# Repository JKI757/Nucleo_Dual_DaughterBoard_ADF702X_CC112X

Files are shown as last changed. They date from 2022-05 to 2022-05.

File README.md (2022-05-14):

## About the Project

- This project is a simple PCB for an STM32 Nucleo-64 Hat that provides an interface between the hat and an Analog Devices [ADF-702X](https://www.analog.com/en/design-center/evaluation-hardware-and-software/evaluation-boards-kits/eval-adf7021-n.html) development board and a Texas Instruments [CC112X EMK](https://www.ti.com/tool/CC1120EMK-420-470) development board.

The project includes both the Kicad schematic and PCB files, and the STM project for the Nucleo-64 L452RE.

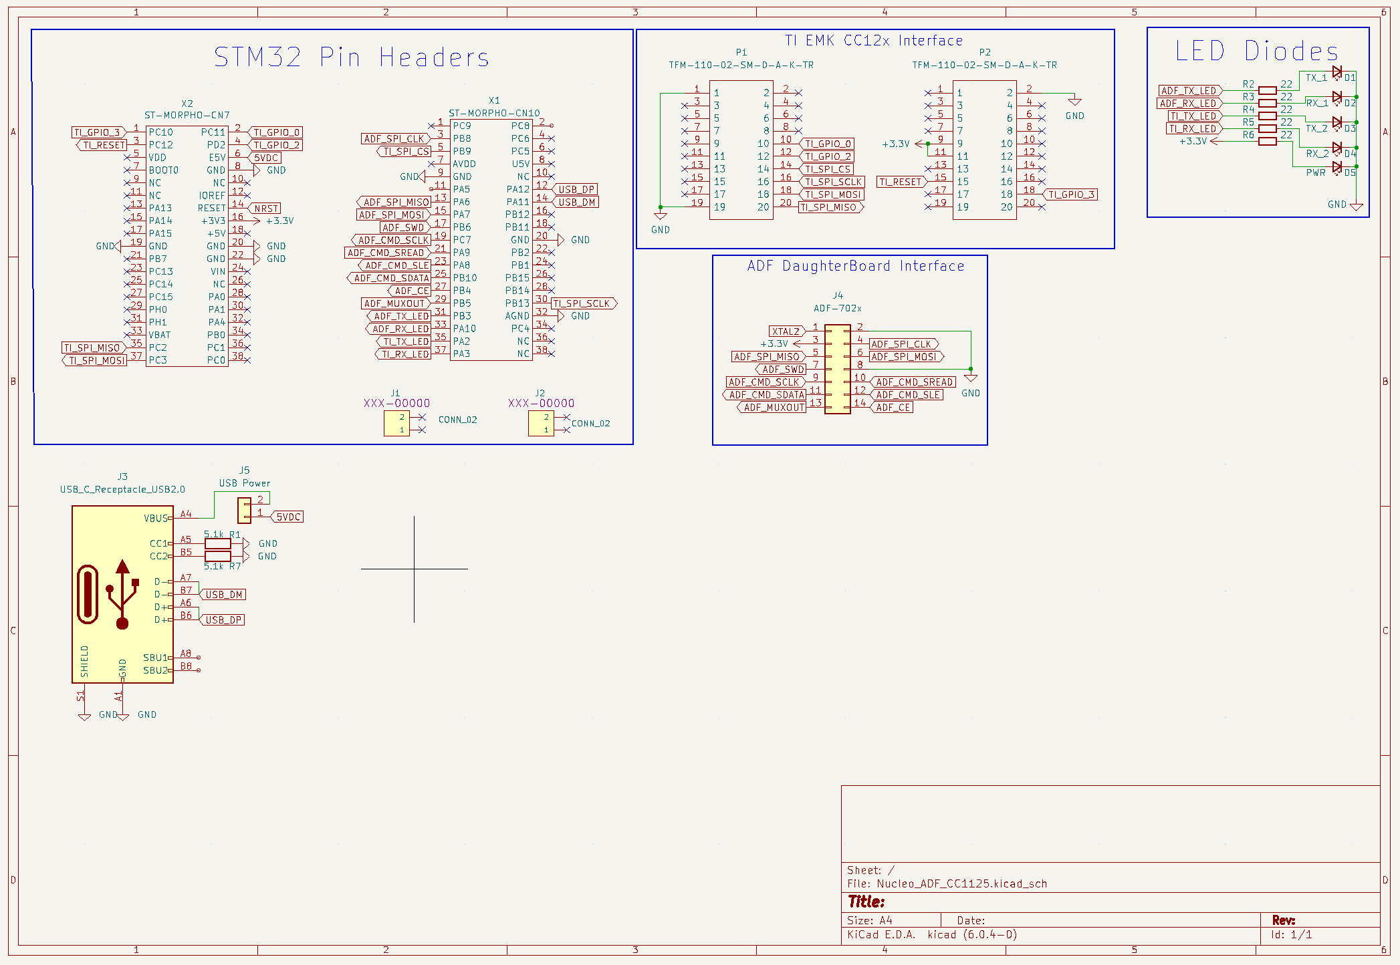
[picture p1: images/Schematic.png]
Schematic


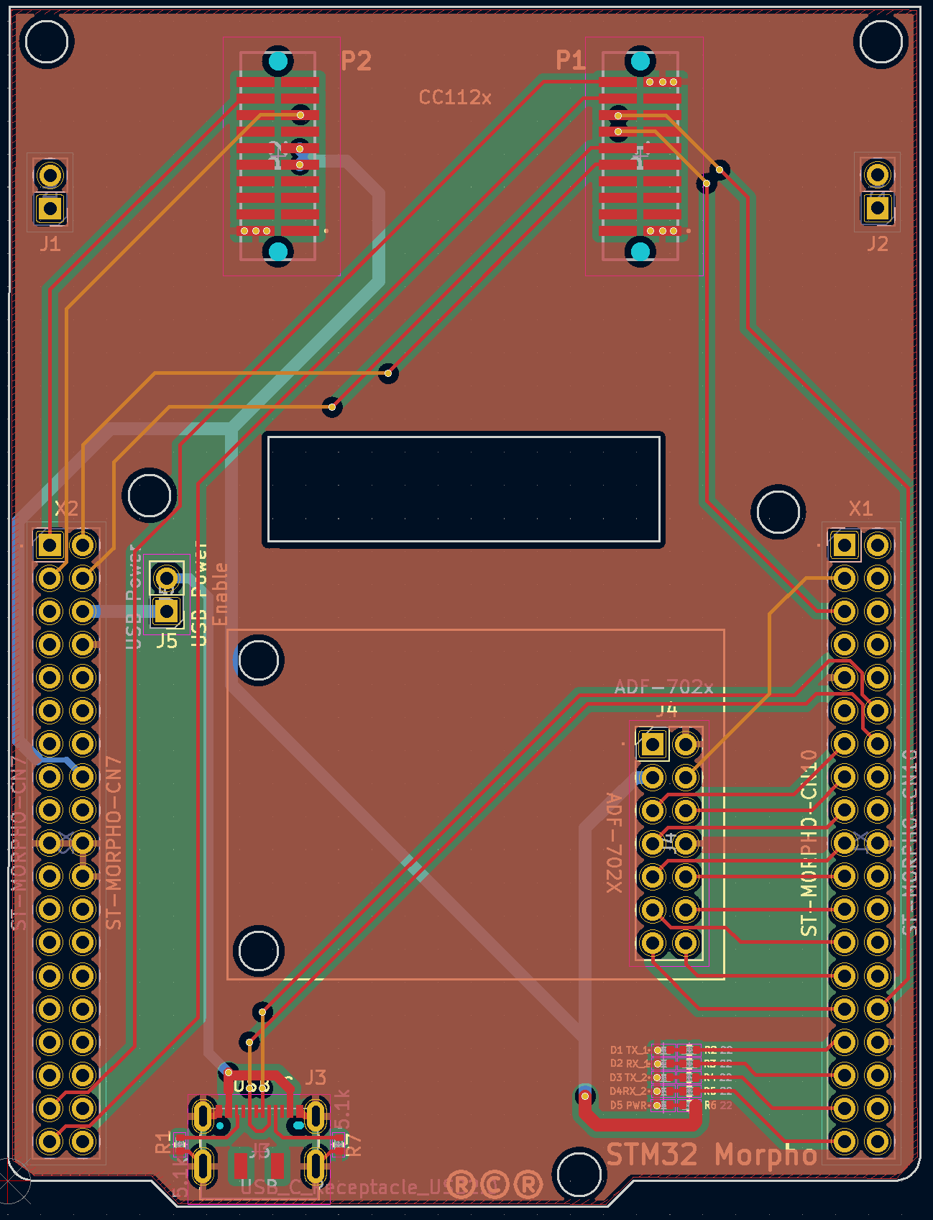
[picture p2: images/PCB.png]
PCB


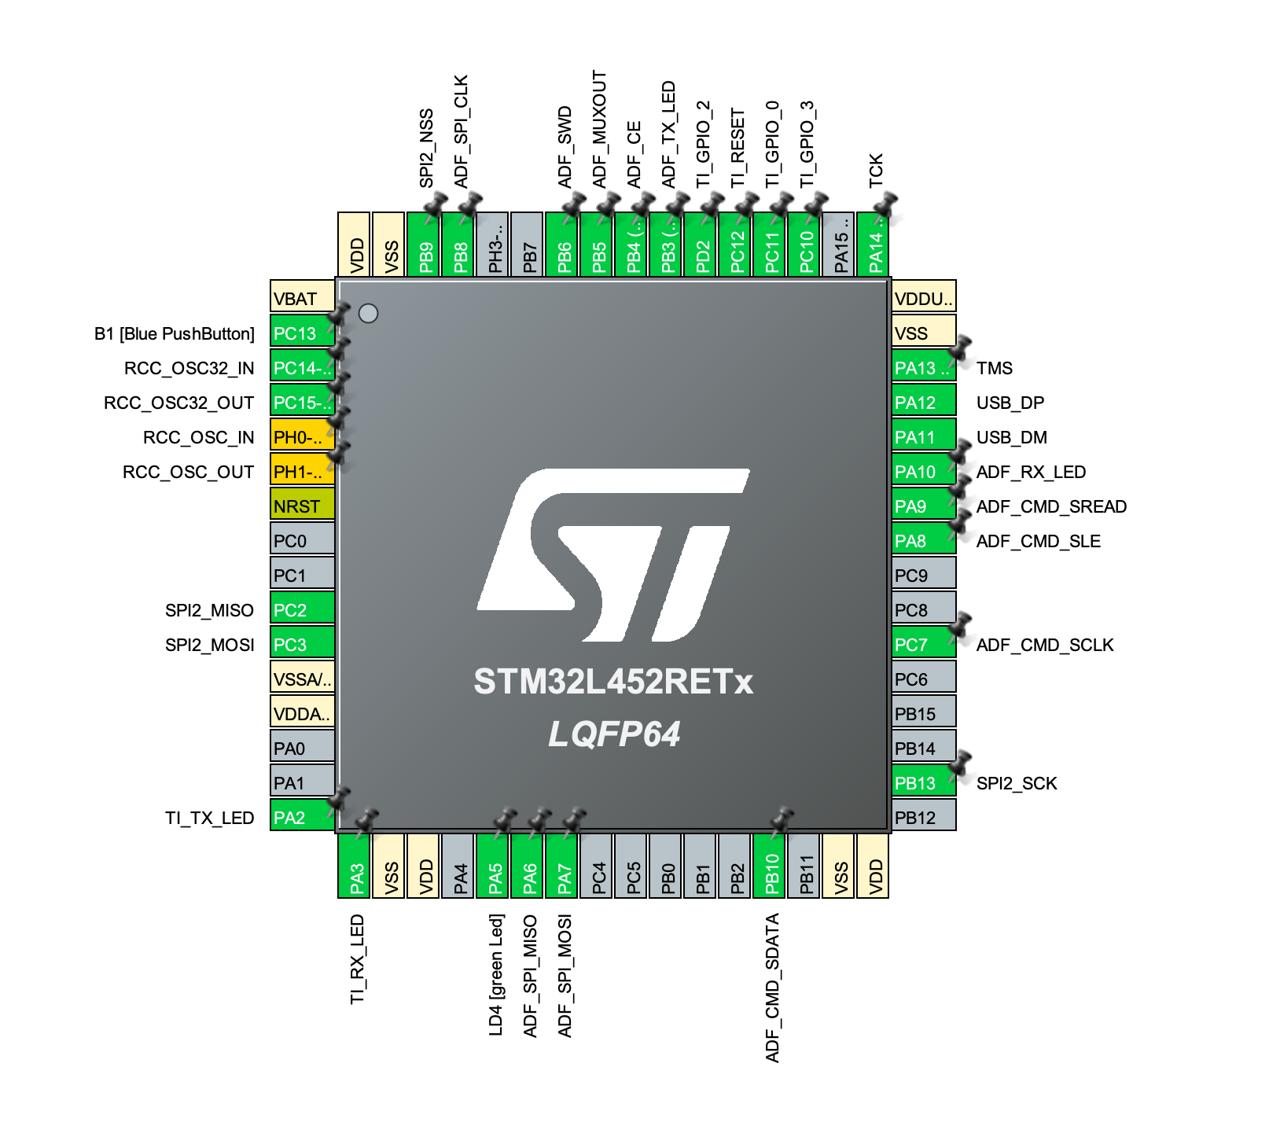
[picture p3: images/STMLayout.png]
Layout STM Layout


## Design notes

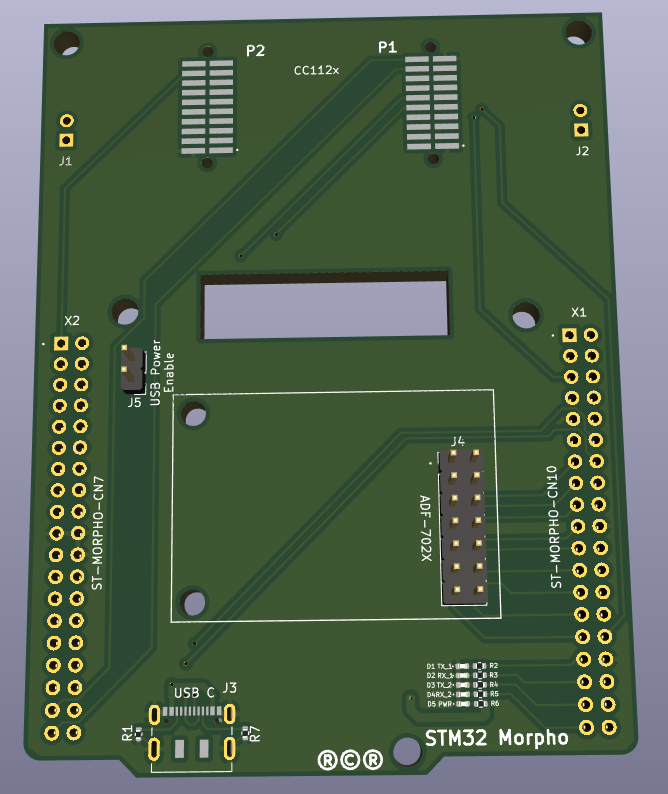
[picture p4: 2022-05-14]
images/3D.png

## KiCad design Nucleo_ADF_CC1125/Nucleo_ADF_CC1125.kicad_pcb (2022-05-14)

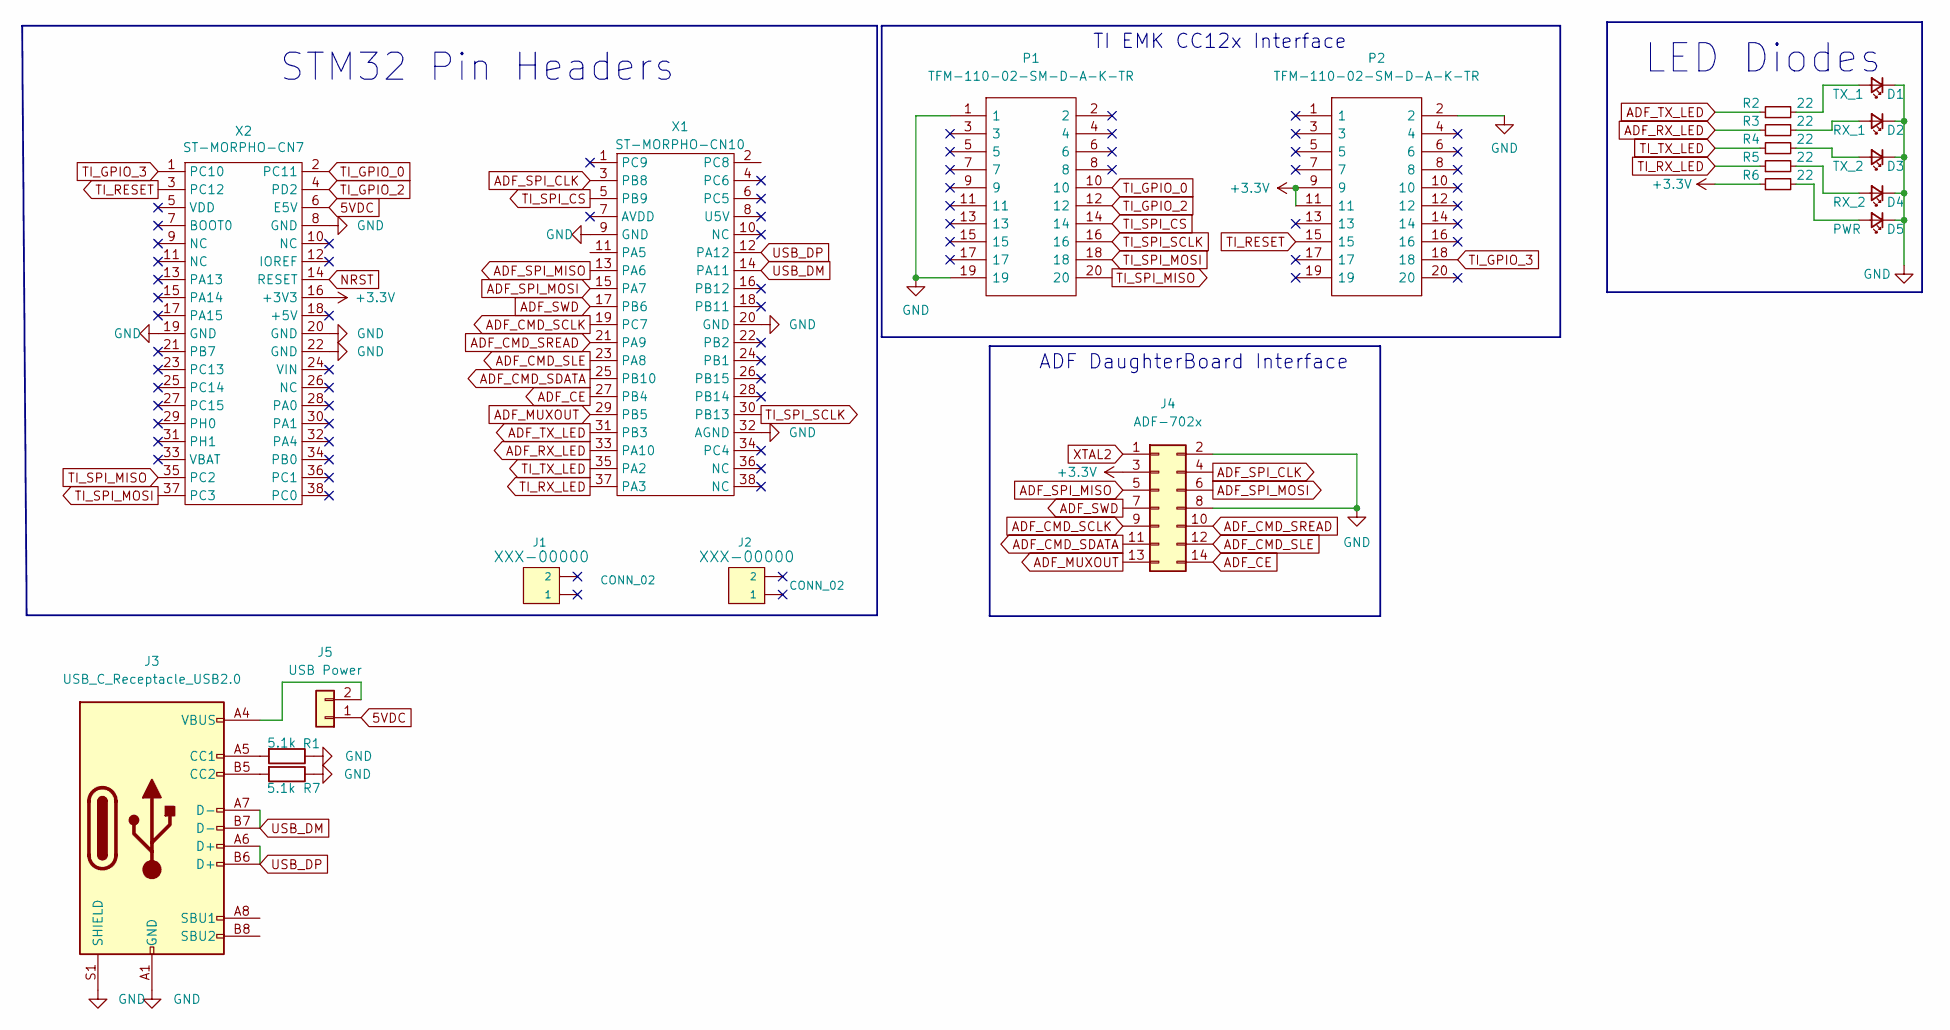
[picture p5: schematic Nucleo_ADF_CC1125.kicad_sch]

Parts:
D1: TX_1; LED_0402_1005Metric
D2: RX_1; LED_0402_1005Metric
D3: TX_2; LED_0402_1005Metric
D4: RX_2; LED_0402_1005Metric
D5: PWR; LED_0402_1005Metric
J1, J2: CONN_02; PinSocket_1x02_P2.54mm_Vertical
J3: USB_C_Receptacle_USB2.0; USB_C_Receptacle_JAE_DX07S016JA1R1500
J4: ADF-702x; PinHeader_2x07_P2.54mm_Vertical
J5: USB Power; PinHeader_1x02_P2.54mm_Vertical
P1, P2: TFM-110-02-SM-D-A-K-TR; TFM-110-02-XXX-D-A-Y-TR; Mouser Part Number 200-TFM11002SMDAKTR
R1, R7: 5.1k; R_0402_1005Metric
R2, R3, R4, R5, R6: 22; R_0402_1005Metric
X1: ST-MORPHO-CN10; PinSocket_2x19_P2.54mm_Vertical
X2: ST-MORPHO-CN7; PinSocket_2x19_P2.54mm_Vertical

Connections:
5VDC: J5.1, X2.6 (E5V)
+3V3: J4.3, P2.9, P2.11, R6.1, X2.16 (+3V3)
ADF_CE: J4.14, X1.27 (PB4)
ADF_CMD_SCLK: J4.9, X1.19 (PC7)
ADF_CMD_SDATA: J4.11, X1.25 (PB10)
ADF_CMD_SLE: J4.12, X1.23 (PA8)
ADF_CMD_SREAD: J4.10, X1.21 (PA9)
ADF_MUXOUT: J4.13, X1.29 (PB5)
ADF_RX_LED: R3.1, X1.33 (PA10)
ADF_SPI_CLK: J4.4, X1.3 (PB8)
ADF_SPI_MISO: J4.5, X1.13 (PA6)
ADF_SPI_MOSI: J4.6, X1.15 (PA7)
ADF_SWD: J4.7, X1.17 (PB6)
ADF_TX_LED: R2.1, X1.31 (PB3)
GND: D1.1 (K), D2.1 (K), D3.1 (K), D4.1 (K), D5.1 (K), J3.A1 (GND), J3.A12 (GND), J3.B1 (GND), J3.B12 (GND), J3.S1 (SHIELD), J4.2, J4.8, P1.1, P1.19, P2.2, R1.1, R7.1, X1.9 (GND), X1.20 (GND), X1.32 (AGND), X2.8 (GND), X2.19 (GND), X2.20 (GND), X2.22 (GND)
NRST: X2.14 (RESET)
unnamed: D1.2 (A), R2.2
unnamed: D2.2 (A), R3.2
unnamed: D3.2 (A), R4.2
unnamed: D4.2 (A), R5.2
unnamed: D5.2 (A), R6.2
unnamed: J3.A4 (VBUS), J3.A9 (VBUS), J3.B4 (VBUS), J3.B9 (VBUS), J5.2
unnamed: J3.A5 (CC1), R1.2
unnamed: J3.B5 (CC2), R7.2
TI_GPIO_0: P1.10, X2.2 (PC11)
TI_GPIO_2: P1.12, X2.4 (PD2)
TI_GPIO_3: P2.18, X2.1 (PC10)
TI_RESET: P2.15, X2.3 (PC12)
TI_RX_LED: R5.1, X1.37 (PA3)
TI_SPI_CS: P1.14, X1.5 (PB9)
TI_SPI_MISO: P1.20, X2.35 (PC2)
TI_SPI_MOSI: P1.18, X2.37 (PC3)
TI_SPI_SCLK: P1.16, X1.30 (PB13)
TI_TX_LED: R4.1, X1.35 (PA2)
USB_DM: J3.A7 (D-), J3.B7 (D-), X1.14 (PA11)
USB_DP: J3.A6 (D+), J3.B6 (D+), X1.12 (PA12)
XTAL2: J4.1

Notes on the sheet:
TI EMK CC12x Interface
STM32 Pin Headers
LED Diodes
ADF DaughterBoard Interface

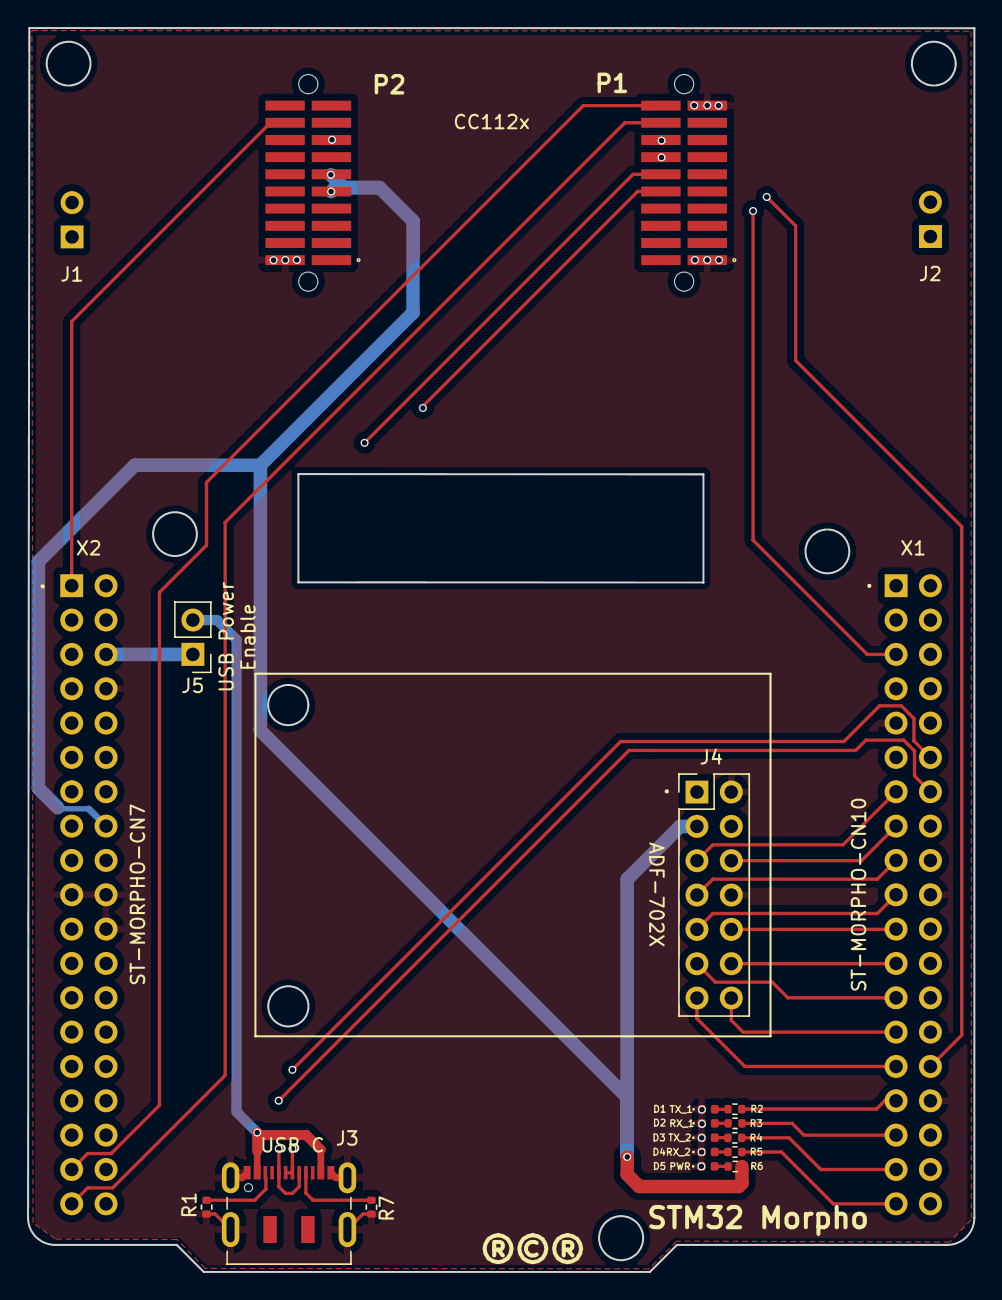
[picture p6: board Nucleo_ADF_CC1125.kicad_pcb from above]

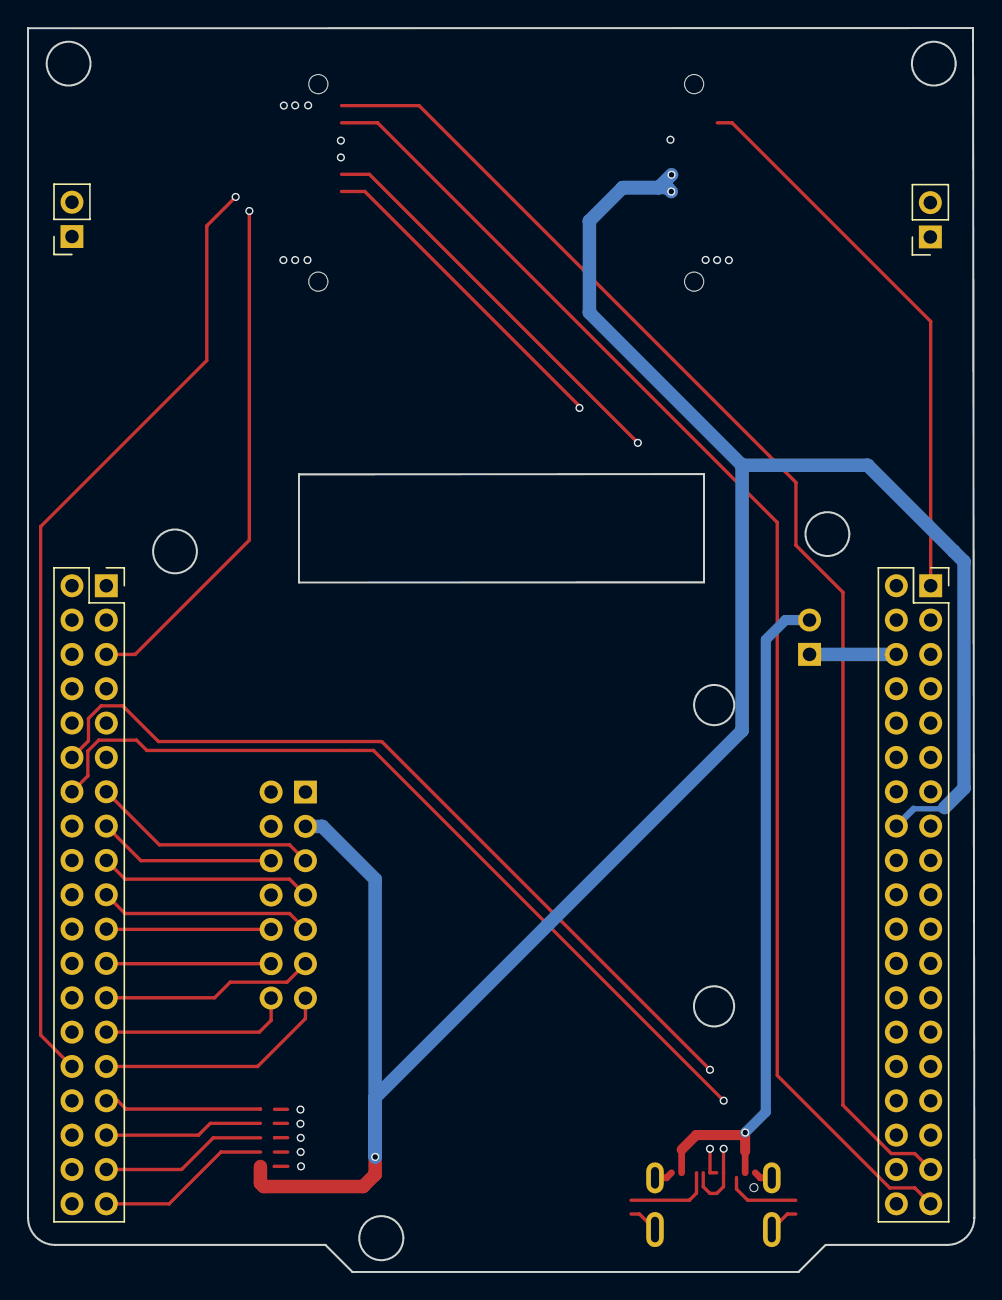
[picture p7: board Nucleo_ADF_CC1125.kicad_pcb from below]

Board: 4 copper layers, 70.0 x 92.0 mm, 21 parts (4 on the bottom side), 35 nets.

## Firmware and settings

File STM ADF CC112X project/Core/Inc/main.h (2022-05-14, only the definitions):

#define B1_Pin LL_GPIO_PIN_13
#define B1_GPIO_Port GPIOC
#define B1_EXTI_IRQn EXTI15_10_IRQn
#define TI_TX_LED_Pin LL_GPIO_PIN_2
#define TI_TX_LED_GPIO_Port GPIOA
#define TI_RX_LED_Pin LL_GPIO_PIN_3
#define TI_RX_LED_GPIO_Port GPIOA
#define LD4_Pin LL_GPIO_PIN_5
#define LD4_GPIO_Port GPIOA
#define ADF_SPI_MISO_Pin LL_GPIO_PIN_6
#define ADF_SPI_MISO_GPIO_Port GPIOA
#define ADF_SPI_MOSI_Pin LL_GPIO_PIN_7
#define ADF_SPI_MOSI_GPIO_Port GPIOA
#define ADF_CMD_SDATA_Pin LL_GPIO_PIN_10
#define ADF_CMD_SDATA_GPIO_Port GPIOB
#define ADF_CMD_SCLK_Pin LL_GPIO_PIN_7
#define ADF_CMD_SCLK_GPIO_Port GPIOC
#define ADF_CMD_SLE_Pin LL_GPIO_PIN_8
#define ADF_CMD_SLE_GPIO_Port GPIOA
#define ADF_CMD_SREAD_Pin LL_GPIO_PIN_9
#define ADF_CMD_SREAD_GPIO_Port GPIOA
#define ADF_RX_LED_Pin LL_GPIO_PIN_10
#define ADF_RX_LED_GPIO_Port GPIOA
#define TMS_Pin LL_GPIO_PIN_13
#define TMS_GPIO_Port GPIOA
#define TCK_Pin LL_GPIO_PIN_14
#define TCK_GPIO_Port GPIOA
#define TI_GPIO_3_Pin LL_GPIO_PIN_10
#define TI_GPIO_3_GPIO_Port GPIOC
#define TI_GPIO_3_EXTI_IRQn EXTI15_10_IRQn
#define TI_GPIO_0_Pin LL_GPIO_PIN_11
#define TI_GPIO_0_GPIO_Port GPIOC
#define TI_GPIO_0_EXTI_IRQn EXTI15_10_IRQn
#define TI_RESET_Pin LL_GPIO_PIN_12
#define TI_RESET_GPIO_Port GPIOC
#define TI_GPIO_2_Pin LL_GPIO_PIN_2
#define TI_GPIO_2_GPIO_Port GPIOD
#define TI_GPIO_2_EXTI_IRQn EXTI2_IRQn
#define ADF_TX_LED_Pin LL_GPIO_PIN_3
#define ADF_TX_LED_GPIO_Port GPIOB
#define ADF_CE_Pin LL_GPIO_PIN_4
#define ADF_CE_GPIO_Port GPIOB
#define ADF_MUXOUT_Pin LL_GPIO_PIN_5
#define ADF_MUXOUT_GPIO_Port GPIOB
#define ADF_SWD_Pin LL_GPIO_PIN_6
#define ADF_SWD_GPIO_Port GPIOB
#define ADF_SWD_EXTI_IRQn EXTI9_5_IRQn
#define ADF_SPI_CLK_Pin LL_GPIO_PIN_8
#define ADF_SPI_CLK_GPIO_Port GPIOB
#define ADF_SPI_CLK_EXTI_IRQn EXTI9_5_IRQn

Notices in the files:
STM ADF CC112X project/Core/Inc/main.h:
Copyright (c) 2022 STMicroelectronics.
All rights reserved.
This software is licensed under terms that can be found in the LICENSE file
